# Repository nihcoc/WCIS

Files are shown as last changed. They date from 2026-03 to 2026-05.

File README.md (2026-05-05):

**WCIS – DIY Irrigation System Using ESP32**
---
WCIS (Wirelessly Controlled Irrigation System) is an ESP32-based smart irrigation controller designed to control a solenoid valve or a SERVO for turning water flow ON and OFF on a daily schedule or manually.

WCIS uses an ESP32 microcontroller to control a 25KG servo through a MOSFET driver circuit and GPIO.
MOSFET is used to control power OUT to the servo as when idle the servo might use power.

Housing is modelled for my valve and should be adjusted according to the valve you have before printing.

The HTML is AI-generated.





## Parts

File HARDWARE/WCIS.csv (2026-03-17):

Value | Qty | Use
PCB | 1 | Electronics
10uF/10V(20%) | 1 | Electronics
0.1uF/50V(10%) | 3 | Electronics
22uF/10V(20%) | 1 | Electronics
22uF | 2 | Electronics
0.1uF | 2 | Electronics
IN4007 | 1 | Electronics
LESD5D5.0CT1G | 3 | Electronics
LED | 1 | Electronics
1N5819 | 2 | Electronics
USB_C_Receptacle_USB2.0_14P | 1 | Electronics
Screw_Terminal_01x02 | 1 | Electronics
SS8050 | 2 | Electronics
IRLML2502TRPBF | 1 | Electronics
22.1K(1%) | 1 | Electronics
47.5k(1%) | 1 | Electronics
2K(5%) | 1 | Electronics
0R | 2 | Electronics
10K(5%) | 3 | Electronics
10K(5%)NC | 1 | Electronics
2K | 1 | Electronics
1K THT | 1 | Electronics
SW_Push | 2 | Electronics
ESP32-WROOM-32 | 1 | Electronics
CP2102N-Axx-xQFN28 | 2 | Electronics
AMS1117-3.3 | 1 | Electronics
5V 3A Power Supply Type- C | 1 | Electronics
Solenoid Valve 5V | 1 | Electronics/Plumbing
10M 1/4" hose and Misting set | 1 | Plumbing
3M 1/3" Hose and Adapter | 1 | Plumbing

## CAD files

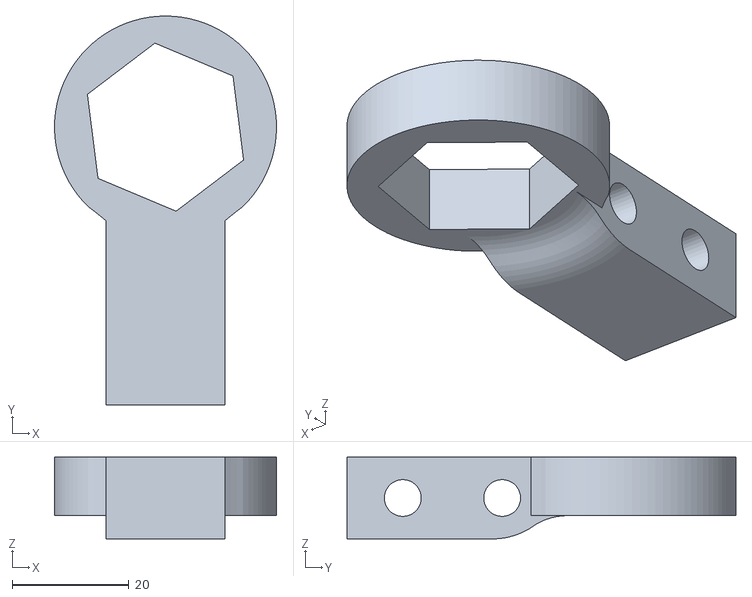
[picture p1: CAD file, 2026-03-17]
HOUSING/Valve Housing.stl
38.0 x 66.6 x 14.0

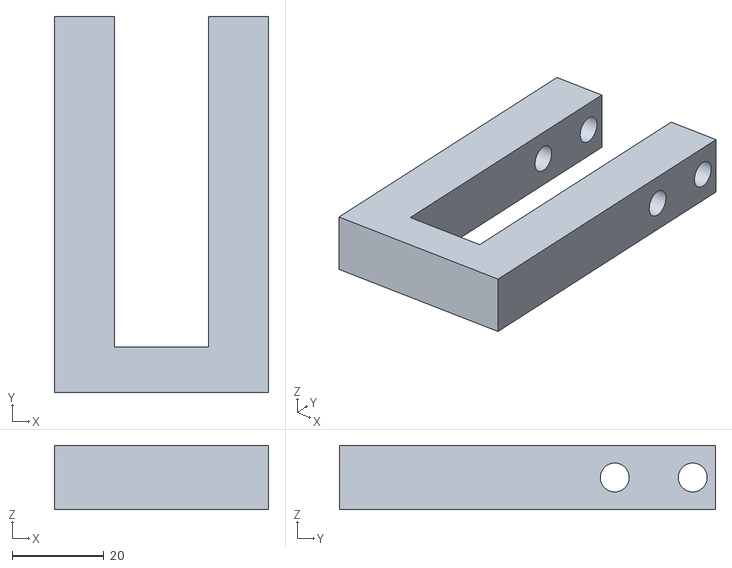
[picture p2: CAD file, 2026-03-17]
HOUSING/HOUSING_BODY.stl
46.7 x 82.0 x 14.0

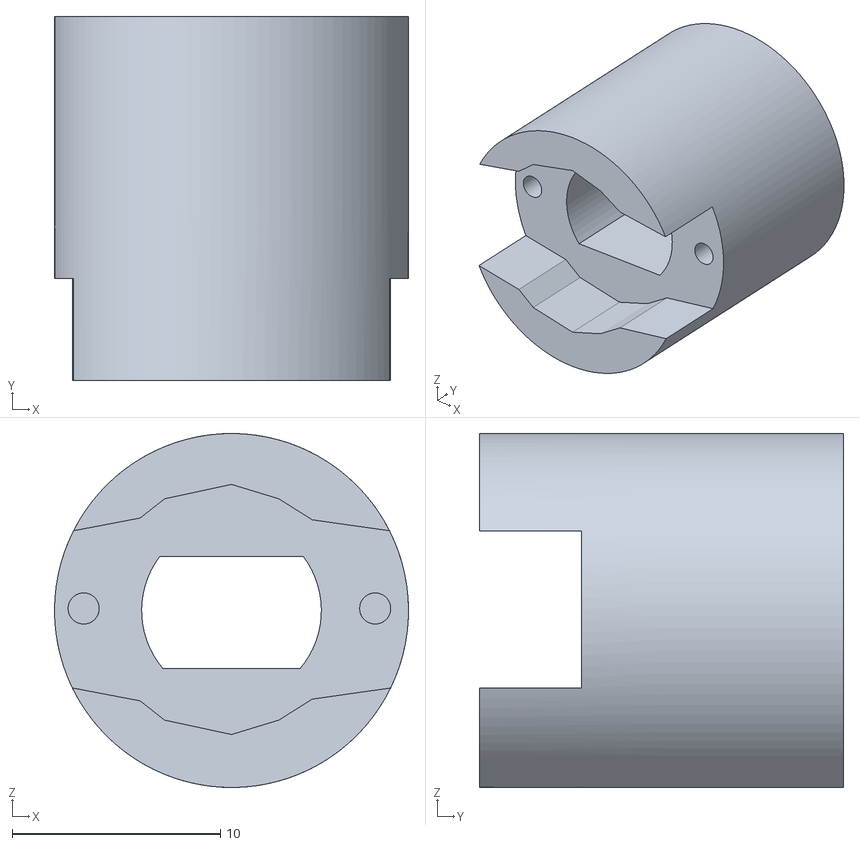
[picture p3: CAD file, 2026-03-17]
HOUSING/Servo Adapter.stl
17.0 x 17.5 x 17.0

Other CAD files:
HOUSING/WCIS Ball Valve housing.f3z

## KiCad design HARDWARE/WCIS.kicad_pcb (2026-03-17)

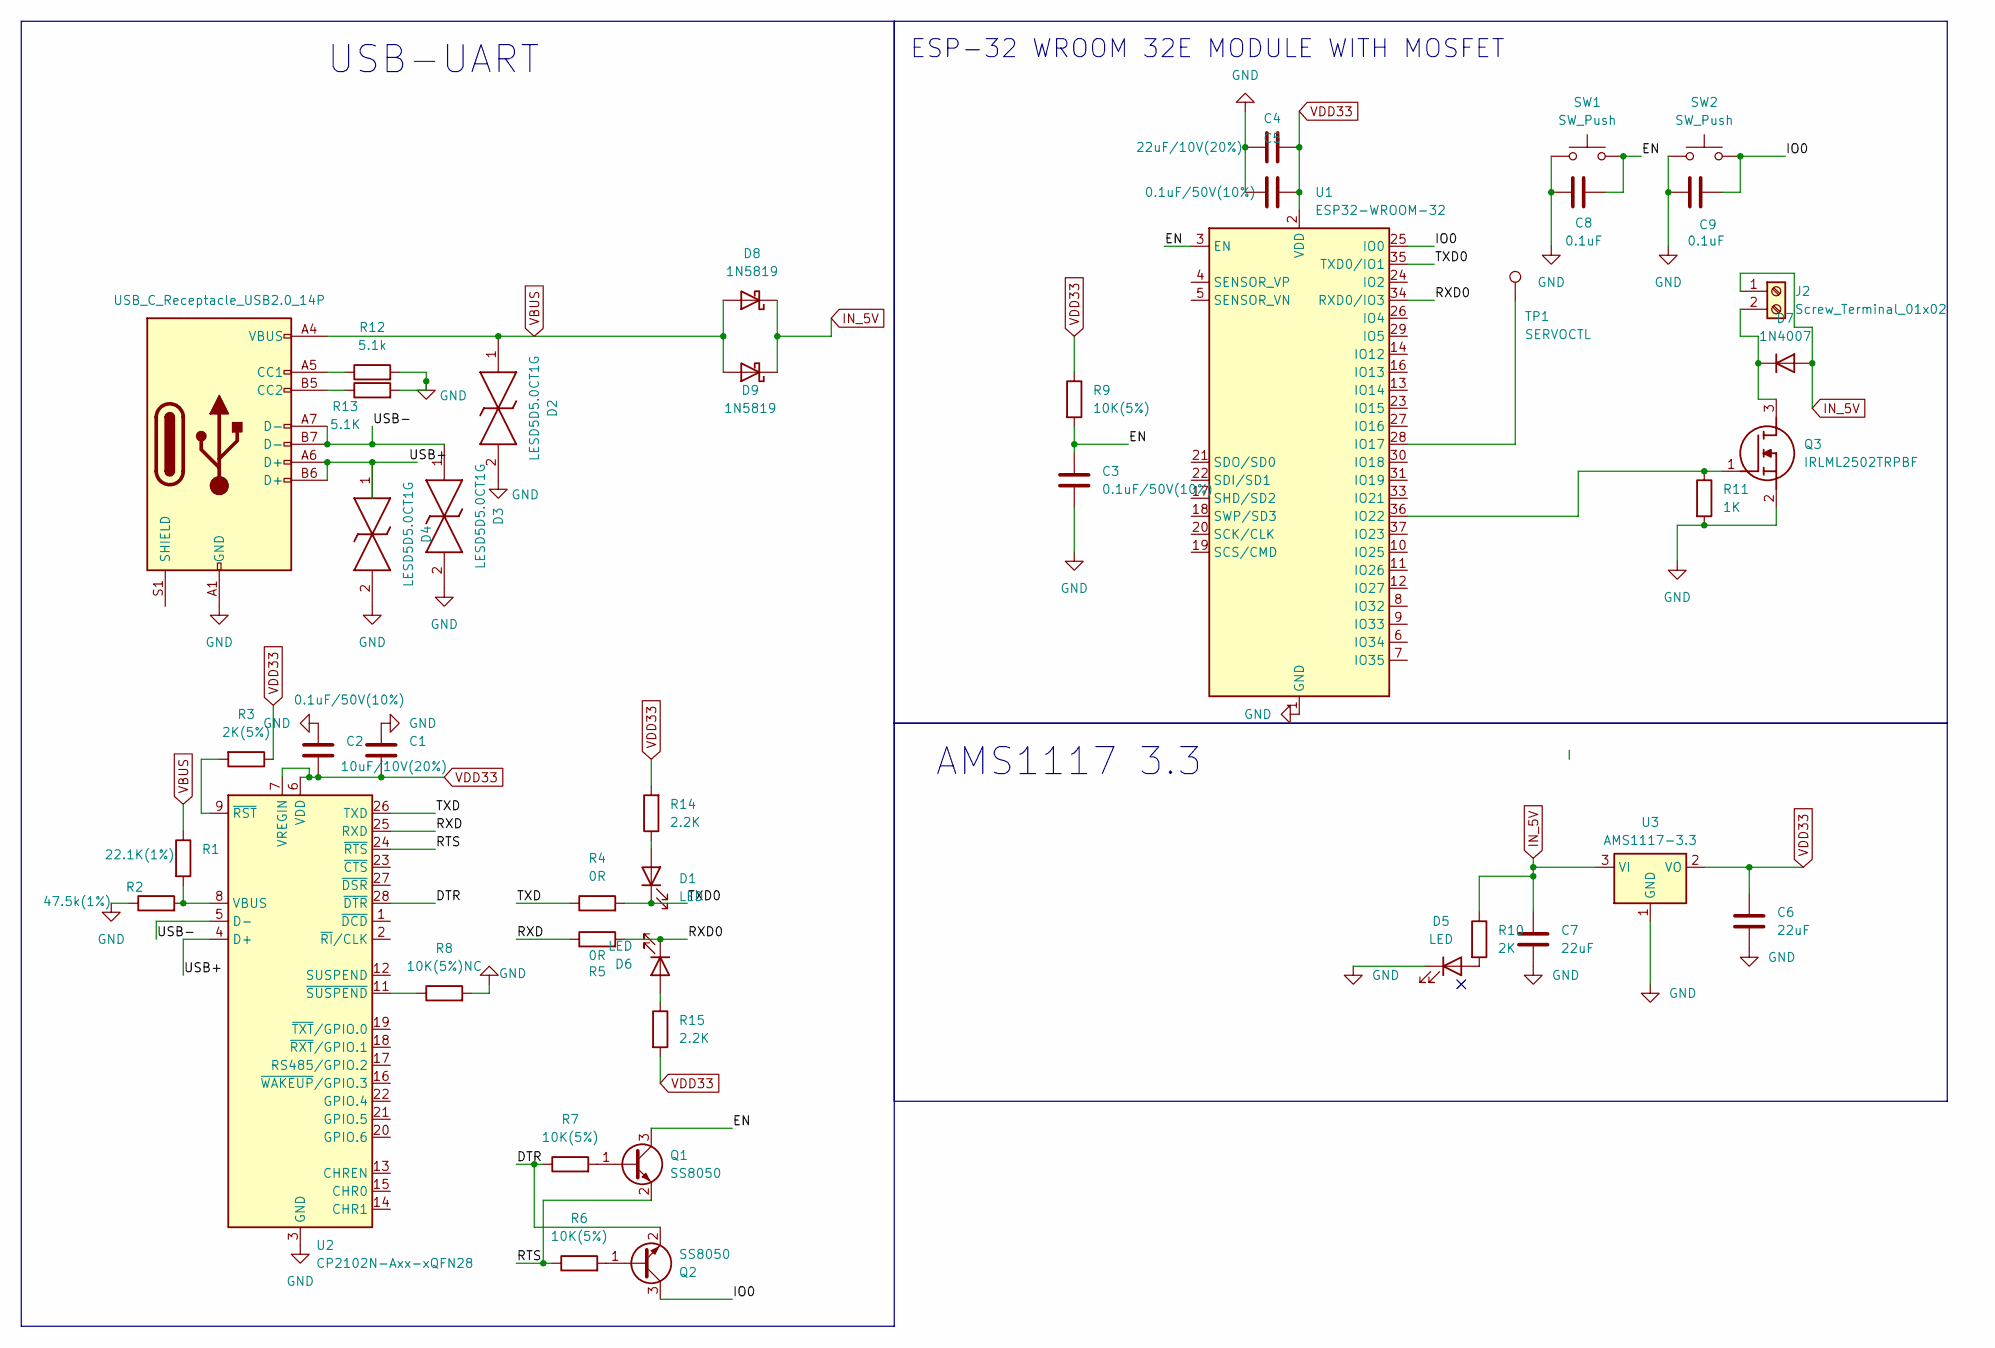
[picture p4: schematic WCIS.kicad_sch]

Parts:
C1: 10uF/10V(20%); C_0805_2012Metric
C2, C3, C5: 0.1uF/50V(10%); C_0805_2012Metric
C4: 22uF/10V(20%); C_0805_2012Metric
C6, C7: 22uF; C_0805_2012Metric
C8, C9: 0.1uF; C_0805_2012Metric
D1, D5, D6: LED; LED_1206_3216Metric
D2, D3, D4: LESD5D5.0CT1G; LESD5D50CT1G; Manufacturer_Part_Number LESD5D5.0CT1G
D7: 1N4007; D_DO-41_SOD81_P10.16mm_Horizontal
D8, D9: 1N5819; D_DO-41_SOD81_P10.16mm_Horizontal
J1: USB_C_Receptacle_USB2.0_14P; USB_C_Receptacle_HCTL_HC-TYPE-C-16P-01A
J2: Screw_Terminal_01x02; TB00475002GR
Q1, Q2: SS8050; SOT-23
Q3: IRLML2502TRPBF; SOT95P237X112-3N; Mouser Part Number 942-IRLML2502TRPBF
R1: 22.1K(1%); R_0805_2012Metric
R2: 47.5k(1%); R_0805_2012Metric
R3: 2K(5%); R_0805_2012Metric
R4, R5: 0R; R_0805_2012Metric
R6, R7, R9: 10K(5%); R_0805_2012Metric
R8: 10K(5%)NC; R_0805_2012Metric
R10: 2K; R_0805_2012Metric
R11: 1K; R_0805_2012Metric
R12: 5.1k; R_0805_2012Metric
R13: 5.1K; R_0805_2012Metric
R14, R15: 2.2K; R_0805_2012Metric
SW1, SW2: SW_Push; SW_PUSH_6mm_H4.3mm
TP1: SERVOCTL; TestPoint_Pad_D2.0mm
U1: ESP32-WROOM-32
U2: CP2102N-Axx-xQFN28; QFN-28-1EP_5x5mm_P0.5mm_EP3.35x3.35mm
U3: AMS1117-3.3; SOT-223-3_TabPin2

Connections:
/DTR: Q2.2 (E), R7.1, U2.28 (~DTR)
/EN: C3.1, C8.2, Q1.3 (C), R9.2, SW1.2, U1.3 (EN)
/IO0: C9.2, Q2.3 (C), SW2.2, U1.25 (IO0)
/RTS: Q1.2 (E), R6.1, U2.24 (~RTS)
/RXD: R5.1, U2.25 (RXD)
/RXD0: D6.1 (K), R5.2, U1.34 (RXD0/IO3)
/TXD: R4.1, U2.26 (TXD)
/TXD0: D1.1 (K), R4.2, U1.35 (TXD0/IO1)
/USB+: D4.1, J1.A6 (D+), J1.B6 (D+), U2.4 (D+)
/USB-: D3.1, J1.A7 (D-), J1.B7 (D-), U2.5 (D-)
GND: C1.1, C2.1, C3.2, C4.1, C5.1, C6.2, C7.2, C8.1, C9.1, D2.2, D3.2, D4.2, D5.1 (K), J1.A1 (GND), J1.A12 (GND), J1.B1 (GND), J1.B12 (GND), Q3.2 (S), R2.1, R8.2, R11.2, R12.2, R13.2, SW1.1, SW2.1, U1.1 (GND), U1.15 (GND), U1.38 (GND), U1.39 (GND), U2.3 (GND), U2.29 (GND), U3.1 (GND)
IN_5V: C7.1, D7.2 (A), D8.1 (K), D9.1 (K), J2.1, R10.1, U3.3 (VI)
unnamed: D1.2 (A), R14.1
unnamed: D5.2 (A), R10.2
unnamed: D6.2 (A), R15.1
unnamed: D7.1 (K), J2.2, Q3.3 (D)
unnamed: J1.A5 (CC1), R12.1
unnamed: J1.B5 (CC2), R13.1
unnamed: Q1.1 (B), R7.2
unnamed: Q2.1 (B), R6.2
unnamed: Q3.1 (G), R11.1, U1.36 (IO22)
unnamed 21: TP1.1, U1.28 (IO17); also elsewhere on the board
unnamed: R1.2, R2.2, U2.8 (VBUS)
unnamed: R3.2, U2.9 (~RST)
unnamed: R8.1, U2.11 (~SUSPEND)
VBUS: D2.1, D8.2 (A), D9.2 (A), J1.A4 (VBUS), J1.A9 (VBUS), J1.B4 (VBUS), J1.B9 (VBUS), R1.1
VDD33: C1.2, C2.2, C4.2, C5.2, C6.1, R3.1, R9.1, R14.2, R15.2, U1.2 (VDD), U2.6 (VDD), U2.7 (VREGIN), U3.2 (VO)

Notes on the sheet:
AMS1117 3.3
USB-UART
ESP-32 WROOM 32E MODULE WITH MOSFET

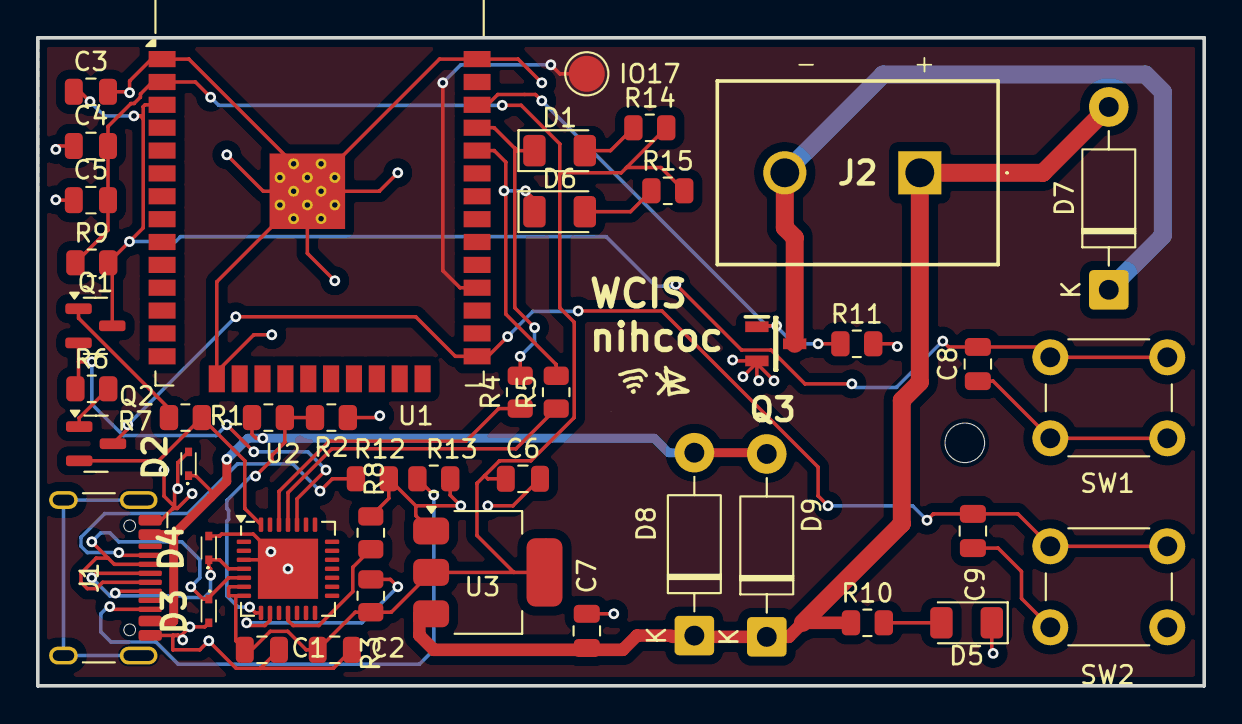
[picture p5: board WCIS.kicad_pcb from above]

Board: 2 copper layers, 64.8 x 36.0 mm, 44 parts (0 on the bottom side), 27 nets.

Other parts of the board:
IO17: SERVOCTL; TestPoint_Pad_D2.0mm

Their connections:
unnamed 21: IO17.1; also elsewhere on the board

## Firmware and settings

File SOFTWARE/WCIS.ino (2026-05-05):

/*
 * ╔══════════════════════════════════════════════════╗
 * ║       ESP32 WATER VALVE SCHEDULER                ║
 * ║  Servo Pin: 17 | Enable Pin: 22                  ║
 * ║  Dual daily schedule via Wi-Fi web interface     ║
 * ╚══════════════════════════════════════════════════╝
 *
 * Libraries required (install via Arduino Library Manager):
 *   - ESP32Servo   by Kevin Harrington
 *   - ArduinoJson  by Benoit Blanchon
 *
 * Board: ESP32 Dev Module
 */
#include <WiFi.h>
#include <WebServer.h>
#include <Preferences.h>
#include <ESP32Servo.h>
#include <ArduinoJson.h>
#include <time.h>
// ─── USER CONFIG ────────────────────────────────────────────────────────────
const char* WIFI_SSID      = "change";
const char* WIFI_PASSWORD  = "chnage";
const char* NTP_SERVER     = "pool.ntp.org";
const long  GMT_OFFSET_S   = 14400;   // UTC+4 Dubai — adjust for your timezone
const int   DAYLIGHT_S     = 0;
const int SERVO_OPEN_DEG   = -40;      // Angle when valve is OPEN
const int SERVO_CLOSE_DEG  = 90;       // Angle when valve is CLOSED
const int VALVE_DURATION_S = 1800;    // Seconds valve stays open (30 min)
// How long (ms) to wait after writing servo position before assuming travel is done.
const unsigned long SERVO_TRAVEL_MS = 10000;
const unsigned long SERVO_ENABLE_SETTLE_MS = 200;
const unsigned long SERVO_HOLD_CLOSED_MS   = 300;
const unsigned long SERVO_DISABLE_GAP_MS   = 20;
const int SERVO_PIN        = 17;
const int SERVO_ENABLE_PIN = 22;
// ────────────────────────────────────────────────────────────────────────────
// ─── VALVE STATE MACHINE ────────────────────────────────────────────────────
enum ValveState {
  VS_IDLE,
  VS_ENABLING,
  VS_MOVING_OPEN,
  VS_OPEN,
  VS_MOVING_CLOSE,
  VS_POWERING_DOWN,
  VS_DISABLE_WAIT
};
ValveState    valveState      = VS_IDLE;
unsigned long stateEnteredAt  = 0;
unsigned long valveOpenAt     = 0;
bool          pendingClose    = false;
Servo       waterValve;
WebServer   server(80);
Preferences prefs;
// ─── SCHEDULE ───────────────────────────────────────────────────────────────
struct Schedule {
  bool    enabled;
  uint8_t hour;
  uint8_t minute;
};
Schedule sched[2];
int lastMinuteChecked = -1;
// ─── NVS HELPERS ────────────────────────────────────────────────────────────
void saveSchedule() {
  prefs.begin("valve", false);
  for (int i = 0; i < 2; i++) {
    String p = "s" + String(i);
    prefs.putBool((p + "en").c_str(), sched[i].enabled);
    prefs.putUChar((p + "h").c_str(), sched[i].hour);
    prefs.putUChar((p + "m").c_str(), sched[i].minute);
  }
  prefs.end();
}
void loadSchedule() {
  prefs.begin("valve", true);
  for (int i = 0; i < 2; i++) {
    String p = "s" + String(i);
    sched[i].enabled = prefs.getBool((p + "en").c_str(), false);
    sched[i].hour    = prefs.getUChar((p + "h").c_str(), 6 + i * 12);
    sched[i].minute  = prefs.getUChar((p + "m").c_str(), 0);
  }
  prefs.end();
}
// ─── TIME HELPERS ───────────────────────────────────────────────────────────
bool tryGetLocalTimeFast(struct tm* out) {
  time_t now = time(nullptr);
  if (now < 24 * 60 * 60) {
    return false;
  }
  localtime_r(&now, out);
  return true;
}
// ─── VALVE HELPERS ──────────────────────────────────────────────────────────
void beginCloseMotion(unsigned long now) {
  pendingClose = false;
  valveState = VS_MOVING_CLOSE;
  stateEnteredAt = now;
  if (!waterValve.attached()) {
    waterValve.attach(SERVO_PIN);
  }
  digitalWrite(SERVO_ENABLE_PIN, HIGH);
  waterValve.write(SERVO_CLOSE_DEG);
}
bool requestOpen() {
  if (valveState != VS_IDLE) {
    return false;
  }
  Serial.println("[VALVE] Open requested");
  pendingClose = false;
  valveState = VS_ENABLING;
  stateEnteredAt = millis();
  digitalWrite(SERVO_ENABLE_PIN, HIGH);
  return true;
}
bool requestClose() {
  if (valveState == VS_IDLE) {
    return false;
  }
  if (valveState == VS_OPEN) {
    Serial.println("[VALVE] Close requested");
    beginCloseMotion(millis());
    return true;
  }
  pendingClose = true;
  return true;
}
// ─── NON-BLOCKING STATE MACHINE ─────────────────────────────────────────────
void updateValveStateMachine() {
  unsigned long now = millis();
  switch (valveState) {
    case VS_IDLE:
      break;
    case VS_ENABLING:
      if (now - stateEnteredAt >= SERVO_ENABLE_SETTLE_MS) {
        waterValve.attach(SERVO_PIN);
        waterValve.write(SERVO_OPEN_DEG);
        valveState = VS_MOVING_OPEN;
        stateEnteredAt = now;
        Serial.println("[VALVE] Moving to OPEN");
      }
      break;
    case VS_MOVING_OPEN:
      if (now - stateEnteredAt >= SERVO_TRAVEL_MS) {
        valveState = VS_OPEN;
        valveOpenAt = now;
        Serial.println("[VALVE] OPEN");
        if (pendingClose) {
          Serial.println("[VALVE] Pending close detected");
          beginCloseMotion(now);
        }
      }
      break;
    case VS_OPEN:
      if (pendingClose ||
          (now - valveOpenAt >= (unsigned long)VALVE_DURATION_S * 1000UL)) {
        Serial.println("[VALVE] Starting close sequence");
        beginCloseMotion(now);
      }
      break;
    case VS_MOVING_CLOSE:
      if (now - stateEnteredAt >= SERVO_TRAVEL_MS) {
        valveState = VS_POWERING_DOWN;
        stateEnteredAt = now;
        Serial.println("[VALVE] Reached CLOSED, holding...");
      }
      break;
    case VS_POWERING_DOWN:
      if (now - stateEnteredAt >= SERVO_HOLD_CLOSED_MS) {
        waterValve.detach();
        valveState = VS_DISABLE_WAIT;
        stateEnteredAt = now;
        Serial.println("[VALVE] PWM detached");
      }
      break;
    case VS_DISABLE_WAIT:
      if (now - stateEnteredAt >= SERVO_DISABLE_GAP_MS) {
        digitalWrite(SERVO_ENABLE_PIN, LOW);
        valveState = VS_IDLE;
        Serial.println("[VALVE] IDLE (power off)");
      }
      break;
  }
}
bool isValveOpen() {
  return valveState == VS_ENABLING ||
         valveState == VS_MOVING_OPEN ||
         valveState == VS_OPEN;
}
bool isScheduleValueValid(int hour, int minute) {
  return hour >= 0 && hour <= 23 && minute >= 0 && minute <= 59;
}
// ─── SCHEDULE CHECK ─────────────────────────────────────────────────────────
void checkSchedule() {
  struct tm t;
  if (!tryGetLocalTimeFast(&t)) {
    return;
  }
  int currentMin = t.tm_hour * 60 + t.tm_min;
  if (currentMin == lastMinuteChecked) {
    return;
  }
  lastMinuteChecked = currentMin;
  for (int i = 0; i < 2; i++) {
    if (!sched[i].enabled) {
      continue;
    }
    if (currentMin == sched[i].hour * 60 + sched[i].minute) {
      Serial.printf("[SCHED] Schedule %d fired at %02d:%02d\n", i, t.tm_hour, t.tm_min);
      requestOpen();
    }
  }
}
// ─── API HANDLERS ───────────────────────────────────────────────────────────
void addCorsHeaders() {
  server.sendHeader("Access-Control-Allow-Origin", "*");
  server.sendHeader("Access-Control-Allow-Headers", "Content-Type");
  server.sendHeader("Access-Control-Allow-Methods", "GET,POST,OPTIONS");
}
void handleOptions() {
  addCorsHeaders();
  server.send(204);
}
void handleGetStatus() {
  struct tm t;
  bool hasTime = tryGetLocalTimeFast(&t);
  char timeBuf[20] = "Syncing...";
  if (hasTime) {
    snprintf(timeBuf, sizeof(timeBuf), "%02d:%02d:%02d", t.tm_hour, t.tm_min, t.tm_sec);
  }
  long remaining = 0;
  if (valveState == VS_OPEN) {
    long elapsed = (long)((millis() - valveOpenAt) / 1000UL);
    remaining = max(0L, (long)VALVE_DURATION_S - elapsed);
  }
  StaticJsonDocument<512> doc;
  doc["valve"] = isValveOpen();
  doc["state"] = (int)valveState;
  doc["remaining"] = remaining;
  doc["time"] = timeBuf;
  doc["ip"] = WiFi.localIP().toString();
  JsonArray arr = doc.createNestedArray("schedules");
  for (int i = 0; i < 2; i++) {
    JsonObject o = arr.createNestedObject();
    o["enabled"] = sched[i].enabled;
    o["hour"] = sched[i].hour;
    o["minute"] = sched[i].minute;
  }
  String out;
  serializeJson(doc, out);
  addCorsHeaders();
  server.send(200, "application/json", out);
}
void handleSetSchedule() {
  if (!server.hasArg("plain")) {
    addCorsHeaders();
    server.send(400, "text/plain", "No body");
    return;
  }
  StaticJsonDocument<256> doc;
  if (deserializeJson(doc, server.arg("plain"))) {
    addCorsHeaders();
    server.send(400, "text/plain", "Bad JSON");
    return;
  }
  int idx    = doc["index"] | -1;
  int hour   = doc["hour"] | -1;
  int minute = doc["minute"] | -1;
  bool en    = doc["enabled"] | false;
  if (idx < 0 || idx > 1) {
    addCorsHeaders();
    server.send(400, "text/plain", "index must be 0 or 1");
    return;
  }
  if (!isScheduleValueValid(hour, minute)) {
    addCorsHeaders();
    server.send(400, "text/plain", "hour must be 0-23 and minute 0-59");
    return;
  }
  sched[idx].enabled = en;
  sched[idx].hour = (uint8_t)hour;
  sched[idx].minute = (uint8_t)minute;
  saveSchedule();
  addCorsHeaders();
  server.send(200, "application/json", "{\"ok\":true}");
  Serial.printf("[API] Schedule %d: %02d:%02d en=%d\n",
    idx, sched[idx].hour, sched[idx].minute, sched[idx].enabled);
}
void handleManualOpen() {
  bool accepted = requestOpen();
  addCorsHeaders();
  server.send(200, "application/json",
    accepted ? "{\"ok\":true,\"action\":\"opening\"}" :
               "{\"ok\":true,\"action\":\"ignored\"}");
}
void handleManualClose() {
  bool accepted = requestClose();
  addCorsHeaders();
  server.send(200, "application/json",
    accepted ? "{\"ok\":true,\"action\":\"closing_or_queued\"}" :
               "{\"ok\":true,\"action\":\"ignored\"}");
}
// ─── EMBEDDED WEB PAGE ──────────────────────────────────────────────────────
void handleRoot() {
  const char* html = R"rawhtml(<!DOCTYPE html>
<html lang="en">
<head>
<meta charset="UTF-8"/>
<meta name="viewport" content="width=device-width,initial-scale=1.0"/>
<title>AquaTimer</title>
<style>
@import url('https://fonts.googleapis.com/css2?family=Share+Tech+Mono&family=Bebas+Neue&display=swap');
:root{
  --bg:#0d0f0e;--surface:#141816;--card:#1a1e1b;--border:#2a3028;
  --accent:#4ade80;--accent2:#86efac;--danger:#f87171;
  --muted:#4a5c4e;--text:#d1fae5;--text-dim:#6b8c72;
  --glow:0 0 24px #4ade8044;
}
*{box-sizing:border-box;margin:0;padding:0}
body{background:var(--bg);color:var(--text);font-family:'Share Tech Mono',monospace;
  min-height:100vh;padding:24px 16px 48px;overflow-x:hidden;position:relative}
body::before{content:'';position:fixed;inset:0;
  background:repeating-linear-gradient(0deg,transparent,transparent 2px,rgba(0,0,0,.06) 2px,rgba(0,0,0,.06) 4px);
  pointer-events:none;z-index:999}
body::after{content:'';position:fixed;inset:0;
  background-image:linear-gradient(var(--border) 1px,transparent 1px),linear-gradient(90deg,var(--border) 1px,transparent 1px);
  background-size:40px 40px;opacity:.3;pointer-events:none;z-index:0}
.wrap{max-width:680px;margin:0 auto;position:relative;z-index:1}
header{text-align:center;margin-bottom:36px;padding-top:12px}
.logo-row{display:flex;align-items:center;justify-content:center;gap:16px;margin-bottom:6px}
.pipe{width:60px;height:3px;border-radius:2px;background:linear-gradient(90deg,transparent,var(--accent))}
.pipe.r{background:linear-gradient(90deg,var(--accent),transparent)}
h1{font-family:'Bebas Neue',cursive;font-size:clamp(2.4rem,8vw,4rem);letter-spacing:.12em;
  color:var(--accent);text-shadow:var(--glow);line-height:1}
.sub{color:var(--text-dim);font-size:.72rem;letter-spacing:.25em;text-transform:uppercase}
#clock{font-family:'Bebas Neue',cursive;font-size:clamp(3rem,12vw,5.5rem);color:var(--accent2);
  letter-spacing:.06em;text-align:center;text-shadow:var(--glow);margin:18px 0 8px}
.card{background:var(--card);border:1px solid var(--border);border-radius:4px;padding:22px;
  margin-bottom:14px;position:relative;overflow:hidden}
.card::before{content:'';position:absolute;top:0;left:0;right:0;height:2px;
  background:linear-gradient(90deg,transparent,var(--accent),transparent);opacity:.5}
.ctitle{font-size:.62rem;letter-spacing:.3em;text-transform:uppercase;color:var(--text-dim);
  margin-bottom:16px;display:flex;align-items:center;gap:10px}
.ctitle::after{content:'';flex:1;height:1px;background:var(--border)}
.vstatus{display:flex;align-items:center;gap:18px}
.orb{width:52px;height:52px;border-radius:50%;border:2px solid var(--muted);
  display:flex;align-items:center;justify-content:center;font-size:1.4rem;transition:all .4s;flex-shrink:0}
.orb.open{border-color:var(--accent);background:#4ade8020;box-shadow:0 0 20px #4ade8066;animation:pulse 2s infinite}
.orb.moving{border-color:#facc15;background:#facc1520;box-shadow:0 0 14px #facc1555;animation:pulse-y 1s infinite}
@keyframes pulse{0%,100%{box-shadow:0 0 16px #4ade8055}50%{box-shadow:0 0 36px #4ade8099}}
@keyframes pulse-y{0%,100%{opacity:1}50%{opacity:.5}}
.vlabel{font-family:'Bebas Neue',cursive;font-size:1.7rem;letter-spacing:.1em;transition:color .3s}
.vlabel.open{color:var(--accent)}.vlabel.closed{color:var(--muted)}.vlabel.moving{color:#facc15}
.vsub{font-size:.68rem;color:var(--text-dim);letter-spacing:.08em;margin-top:4px}
#countdown{font-size:.72rem;color:var(--accent2);letter-spacing:.1em;margin-top:6px;min-height:1.2em}
.brow{display:grid;grid-template-columns:1fr 1fr;gap:12px;margin-top:18px}
button{font-family:'Share Tech Mono',monospace;font-size:.78rem;letter-spacing:.15em;text-transform:uppercase;
  padding:13px 10px;border-radius:3px;border:1px solid;cursor:pointer;transition:all .2s;background:transparent}
.bo{border-color:var(--accent);color:var(--accent)}
.bo:hover,.bo:active{background:var(--accent);color:var(--bg);box-shadow:var(--glow)}
.bc{border-color:var(--danger);color:var(--danger)}
.bc:hover,.bc:active{background:var(--danger);color:var(--bg);box-shadow:0 0 20px #f8717155}
.slot{padding:16px;border:1px solid var(--border);border-radius:3px;margin-bottom:12px;
  background:var(--surface);transition:border-color .3s}
.slot.active{border-color:#2a3a2e}
.sh{display:flex;align-items:center;justify-content:space-between;margin-bottom:14px}
.snum{font-family:'Bebas Neue',cursive;font-size:1.15rem;color:var(--text-dim);letter-spacing:.1em}
.toggle{position:relative;width:44px;height:24px}
.toggle input{opacity:0;width:0;height:0}
.slider{position:absolute;inset:0;background:var(--border);border-radius:24px;cursor:pointer;transition:.3s}
.slider::before{content:'';position:absolute;width:18px;height:18px;left:3px;top:3px;
  background:var(--muted);border-radius:50%;transition:.3s}
input:checked+.slider{background:#1f3a26}
input:checked+.slider::before{transform:translateX(20px);background:var(--accent);box-shadow:0 0 8px var(--accent)}
.trow{display:flex;align-items:center;gap:10px}
.tlbl{font-size:.62rem;color:var(--text-dim);letter-spacing:.2em;text-transform:uppercase;min-width:52px}
.tinp{display:flex;align-items:center;gap:6px}
.tinp select{background:var(--bg);color:var(--accent);border:1px solid var(--border);border-radius:3px;
  padding:8px 10px;font-family:'Share Tech Mono',monospace;font-size:1rem;cursor:pointer;
  appearance:none;-webkit-appearance:none;width:64px;text-align:center}
.tinp select:focus{outline:none;border-color:var(--accent)}
.tsep{color:var(--accent);font-size:1.2rem;font-family:'Bebas Neue',cursive}
.sbar{display:flex;align-items:center;justify-content:space-between;padding:10px 14px;
  background:var(--surface);border:1px solid var(--border);border-radius:3px;
  font-size:.62rem;color:var(--text-dim);letter-spacing:.1em;margin-bottom:14px}
.dot{width:7px;height:7px;border-radius:50%;background:var(--accent);
  box-shadow:0 0 6px var(--accent);animation:blink 2s infinite;display:inline-block;margin-right:6px}
@keyframes blink{0%,100%{opacity:1}50%{opacity:.3}}
#toast{position:fixed;bottom:28px;left:50%;transform:translateX(-50%);background:var(--card);
  border:1px solid var(--accent);color:var(--accent);padding:10px 24px;border-radius:3px;
  font-size:.72rem;letter-spacing:.15em;opacity:0;pointer-events:none;transition:opacity .3s;
  z-index:1000;white-space:nowrap}
#toast.show{opacity:1}
@media(max-width:400px){.brow{grid-template-columns:1fr}}
</style>
</head>
<body>
<div class="wrap">
<header>
  <div class="logo-row">
    <div class="pipe"></div>
    <h1>AQUATIMER</h1>
    <div class="pipe r"></div>
  </div>
  <p class="sub">ESP32 &middot; Valve Scheduler &middot; GPIO 17</p>
</header>
<div class="sbar">
  <span><span class="dot"></span>ONLINE</span>
  <span id="ip-disp">—</span>
  <span>EN: GPIO22</span>
</div>
<div id="clock">--:--:--</div>
<div class="card">
  <div class="ctitle">Valve Status</div>
  <div class="vstatus">
    <div class="orb" id="orb">💧</div>
    <div>
      <div class="vlabel closed" id="vlbl">CLOSED</div>
      <div class="vsub" id="vsub">Idle</div>
      <div id="countdown"></div>
    </div>
  </div>
  <div class="brow">
    <button class="bo" onclick="manualOpen()">&#9654; Open Valve</button>
    <button class="bc" onclick="manualClose()">&#9632; Close Valve</button>
  </div>
</div>
<div class="card">
  <div class="ctitle">Daily Schedules</div>
  <div class="slot" id="slot-0">
    <div class="sh">
      <span class="snum">SCHEDULE 01</span>
      <label class="toggle"><input type="checkbox" id="en0" onchange="saveSched(0)"/><span class="slider"></span></label>
    </div>
    <div class="trow">
      <span class="tlbl">TIME</span>
      <div class="tinp">
        <select id="h0" onchange="saveSched(0)"></select>
        <span class="tsep">:</span>
        <select id="m0" onchange="saveSched(0)"></select>
      </div>
    </div>
  </div>
  <div class="slot" id="slot-1">
    <div class="sh">
      <span class="snum">SCHEDULE 02</span>
      <label class="toggle"><input type="checkbox" id="en1" onchange="saveSched(1)"/><span class="slider"></span></label>
    </div>
    <div class="trow">
      <span class="tlbl">TIME</span>
      <div class="tinp">
        <select id="h1" onchange="saveSched(1)"></select>
        <span class="tsep">:</span>
        <select id="m1" onchange="saveSched(1)"></select>
      </div>
    </div>
  </div>
</div>
</div>
<div id="toast"></div>
<script>
const VS_IDLE=0,VS_ENABLING=1,VS_MOVING_OPEN=2,VS_OPEN=3,VS_MOVING_CLOSE=4,VS_POWERING_DOWN=5,VS_DISABLE_WAIT=6;
['h0','h1'].forEach(id=>{
  const el=document.getElementById(id);
  for(let i=0;i<24;i++){const o=document.createElement('option');o.value=i;o.textContent=String(i).padStart(2,'0');el.appendChild(o);}
});
['m0','m1'].forEach(id=>{
  const el=document.getElementById(id);
  for(let i=0;i<60;i++){const o=document.createElement('option');o.value=i;o.textContent=String(i).padStart(2,'0');el.appendChild(o);}
});
function toast(msg){
  const t=document.getElementById('toast');
  t.textContent=msg;t.classList.add('show');
  setTimeout(()=>t.classList.remove('show'),2200);
}
function fmtTime(sec){
  const m=Math.floor(sec/60),s=sec%60;
  return String(m).padStart(2,'0')+':'+String(s).padStart(2,'0')+' remaining';
}
function updateValve(valve, state, remaining){
  const orb=document.getElementById('orb');
  const lbl=document.getElementById('vlbl');
  const sub=document.getElementById('vsub');
  const cd =document.getElementById('countdown');
  if(state===VS_ENABLING||state===VS_MOVING_OPEN){
    orb.className='orb moving';
    lbl.className='vlabel moving';lbl.textContent='OPENING';
    sub.textContent='Servo moving \xb7 Pin 22 active';
    cd.textContent='';
  } else if(state===VS_OPEN){
    orb.className='orb open';
    lbl.className='vlabel open';lbl.textContent='OPEN';
    sub.textContent='Valve open \xb7 Pin 22 active';
    cd.textContent=remaining>0?fmtTime(remaining):'';
  } else if(state===VS_MOVING_CLOSE||state===VS_POWERING_DOWN||state===VS_DISABLE_WAIT){
    orb.className='orb moving';
    lbl.className='vlabel moving';lbl.textContent='CLOSING';
    sub.textContent='Servo moving \xb7 Pin 22 active';
    cd.textContent='';
  } else {
    orb.className='orb';
    lbl.className='vlabel closed';lbl.textContent='CLOSED';
    sub.textContent='Idle \xb7 Pin 22 off';
    cd.textContent='';
  }
}
async function fetchStatus(){
  try{
    const d=await(await fetch('/api/status')).json();
    document.getElementById('clock').textContent=d.time;
    document.getElementById('ip-disp').textContent=d.ip;
    updateValve(d.valve, d.state, d.remaining);
    d.schedules.forEach((s,i)=>{
      document.getElementById('en'+i).checked=s.enabled;
      document.getElementById('h'+i).value=s.hour;
      document.getElementById('m'+i).value=s.minute;
      document.getElementById('slot-'+i).classList.toggle('active',s.enabled);
    });
  }catch(e){}
}
async function saveSched(idx){
  const p={index:idx,enabled:document.getElementById('en'+idx).checked,
    hour:parseInt(document.getElementById('h'+idx).value,10),
    minute:parseInt(document.getElementById('m'+idx).value,10)};
  document.getElementById('slot-'+idx).classList.toggle('active',p.enabled);
  try{
    const r=await fetch('/api/schedule',{method:'POST',headers:{'Content-Type':'application/json'},body:JSON.stringify(p)});
    if(!r.ok){throw new Error('save failed');}
    toast('SCH 0'+(idx+1)+' \u2192 '+String(p.hour).padStart(2,'0')+':'+String(p.minute).padStart(2,'0')+(p.enabled?' ON':' OFF'));
  }catch(e){toast('ERROR');}
}
async function manualOpen(){
  try{
    const r=await fetch('/api/open',{method:'POST'});
    if(!r.ok){throw new Error('open failed');}
    toast('OPEN REQUESTED');
  }catch(e){toast('ERROR');}
}
async function manualClose(){
  try{
    const r=await fetch('/api/close',{method:'POST'});
    if(!r.ok){throw new Error('close failed');}
    toast('CLOSE REQUESTED');
  }catch(e){toast('ERROR');}
}
fetchStatus();
setInterval(fetchStatus,1000);
</script>
</body>
</html>)rawhtml";
  server.send(200, "text/html", html);
}
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
void loop() {
  server.handleClient();
  updateValveStateMachine();
  static unsigned long lastChk = 0;
  if (millis() - lastChk >= 1000) {
    lastChk = millis();
    checkSchedule();
  }
}

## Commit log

2026-03-07 Tested servo control code for ESP32
2026-03-17 Crucial changes in the PCB design.
    Crucial changes in power management were added. Added support for a servo. Reordered files
    [WCIS.csv, WCIS.kicad_pcb, WCIS.kicad_sch]
2026-03-17 3d files of the Housing
    [HOUSING_BODY.stl, Servo Adapter.stl, Valve Housing.stl]
2026-03-30 Revise README for clarity and additional details
    Updated project description and details about the housing and power control.
